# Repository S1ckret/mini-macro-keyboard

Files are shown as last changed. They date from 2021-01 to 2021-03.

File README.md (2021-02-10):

# mini-macro-keyboard

View this project on [CADLAB.io](https://cadlab.io/project/23724). 

## Cloning

After cloning you need to configure (localy to repository) commit message template and init submodules. This will **NOT** override your global configuration.

```sh
git clone https://github.com/S1ckret/mini-macro-keyboard.git

cd mini-macro-keyboard

git config commit.template ./.git-commit-temlate

git submodule update --init
```

You are ready to work!

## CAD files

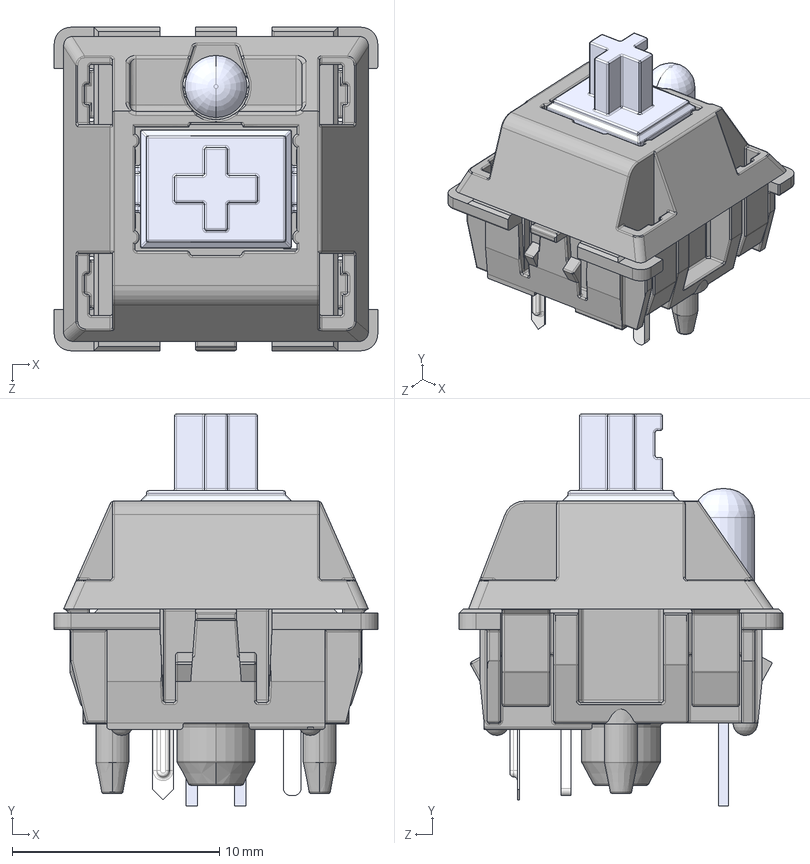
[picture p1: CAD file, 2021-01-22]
hw/mini-macro-keyboard-eco/models/MX.STEP
15.6 x 18.9 x 15.6 mm
MX 轴 按键′_ü___¨1
MX 轴 轴体áì_¨￠¨__
MX粣 拸簽LEDLEDLED
MX轴 轴体 底部 μ×2__默认_á2____è_
针脚___默认__è_

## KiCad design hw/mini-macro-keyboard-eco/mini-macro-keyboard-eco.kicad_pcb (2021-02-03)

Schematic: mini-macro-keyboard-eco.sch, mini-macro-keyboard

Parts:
C0, C1: 12p; C_0402_1005Metric; LCSC Part # C1547
C2, C3, C7: 100n; C_0402_1005Metric; LCSC Part # C1525
C4: 4.7u; C_0402_1005Metric; LCSC Part # C19666
C5, C6: 1u; C_0402_1005Metric; LCSC Part # C52923
D1, D2, D3: BLUE; LED_0603_1608Metric; LCSC Part # C72041
H1, H2, H3, H4: MountingHole_Pad; MountingHole_2.2mm_M2_ISO7380_Pad
J0: USB; USB_Micro-B_Molex-105017-0001
J1: DEBUG_SWD; PinHeader_1x04_P2.54mm_Horizontal
R0: 47; R_0402_1005Metric; LCSC Part # C25792
R1, R2, R3: 330; R_0603_1608Metric; LCSC Part # C23138
R5, R6: 10k; R_0402_1005Metric; LCSC Part # C25744
SW1, SW2, SW3: SW_Cherry_MX_1.00u_PCB
SW5: LAYOUT; SW_SPDT_PCM12
SW6: BACKLIGHT; SW_SPDT_PCM12
U1: USBLC6-2SC6; SOT-23-6; LCSC Part # C7519
U2: XC6206P322MR; SOT-23; LCSC Part # C5446
U3: STM32F070F6P6; TSSOP-20_4.4x6.5mm_P0.65mm; LCSC Part # C86951
Y1: 16 MHz; Crystal_SMD_3225-4Pin_3.2x2.5mm; LCSC Part # C13738

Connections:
+3V3: C2.1, C3.1, C4.1, C6.1, C7.1, J1.1, SW5.1 (A), SW6.1 (A), U2.2 (VO), U3.5 (VDDA), U3.16 (VDD)
+5V: C5.1, J0.1 (VBUS), U1.5 (VBUS), U2.3 (VI)
GND: C0.1, C1.1, C2.2, C3.2, C4.2, C5.2, C6.2, C7.2, H1.1, H2.1, H3.1, H4.1, J0.4 (ID), J0.5 (GND), J1.4, R1.2, R2.2, R3.2, SW1.1, SW2.1, SW3.1, SW5.3 (C), SW6.3 (C), U1.2 (GND), U2.1 (GND), U3.1 (BOOT0), U3.15 (VSS), Y1.2, Y1.4
LED_1: D1.2 (A), U3.9 (PA3)
LED_2: D2.2 (A), U3.7 (PA1)
LED_3: D3.2 (A), U3.6 (PA0)
unnamed: D1.1 (K), R1.1
unnamed: D2.1 (K), R2.1
unnamed: D3.1 (K), R3.1
unnamed: R5.2, SW5.2 (B)
unnamed: R6.2, SW6.2 (B)
OSC_IN: C0.2, U3.2 (PF0), Y1.1
OSC_OUT: C1.2, U3.3 (PF1), Y1.3
SWCLK: J1.3, U3.20 (PA14)
SWDIO: J1.2, U3.19 (PA13)
SW_1: SW1.2, U3.13 (PA7)
SW_2: SW2.2, U3.12 (PA6)
SW_3: SW3.2, U3.11 (PA5)
SW_BACKLIGHT: R6.1, U3.10 (PA4)
SW_LAYOUT: R5.1, U3.14 (PB1)
USB_CONN_D+: J0.3 (D+), U1.3 (I/O2)
USB_CONN_D-: J0.2 (D-), U1.1 (I/O1)
USB_D+: U1.4 (I/O2), U3.18 (PA10/PA12)
USB_D-: U1.6 (I/O1), U3.17 (PA9/PA11)

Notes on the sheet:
Oscillator 16 MHz
USB 2.0 FS
Low dropout regulator (100 mA max)
STM32 Microcontroller
LEDs
Mechanical key switches
Debug SWD connector
Note: STM32F070F6P6 has internal D+ pull up resistor
Switches
Note: Each pin will have internal pull-up resistor
Mounting Holes

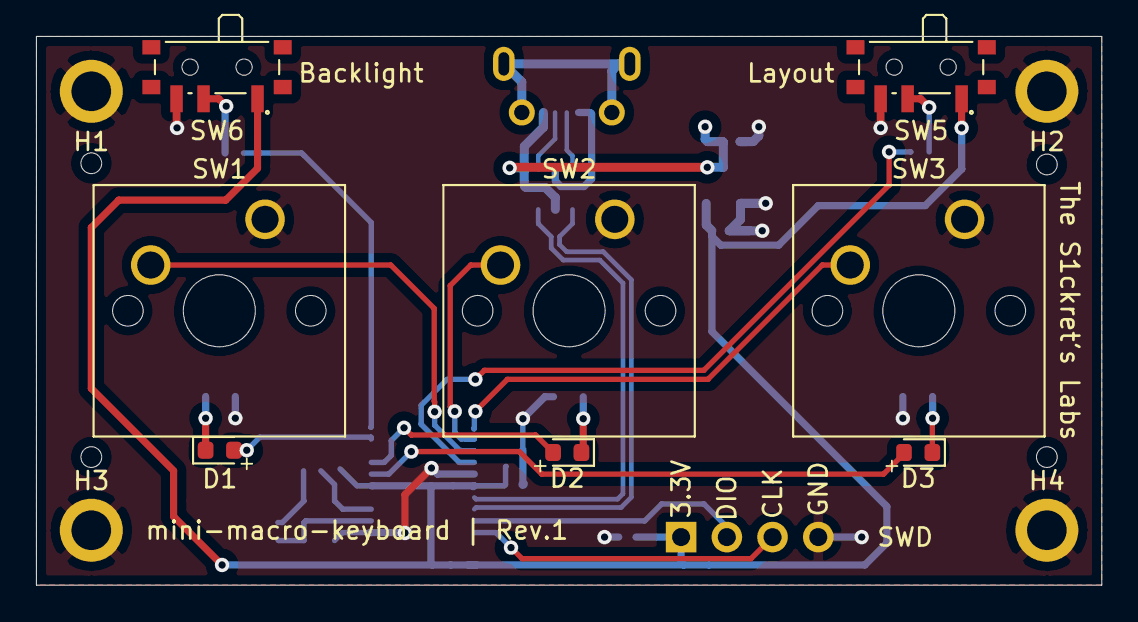
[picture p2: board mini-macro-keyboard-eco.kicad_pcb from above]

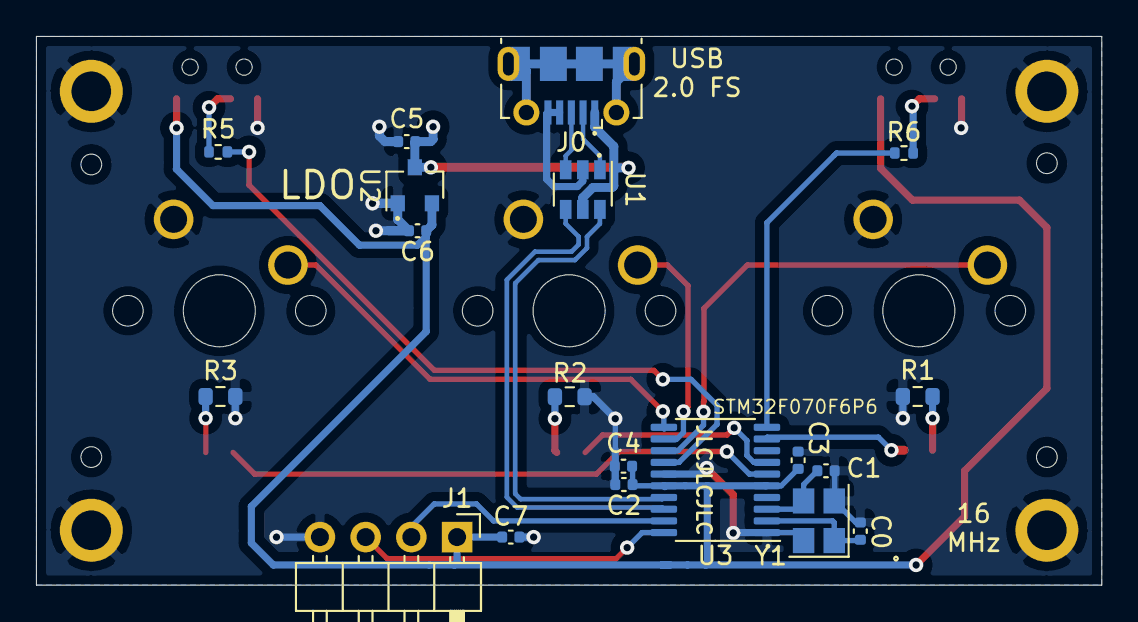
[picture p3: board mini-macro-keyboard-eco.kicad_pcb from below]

Board: 2 copper layers, 59.2 x 30.5 mm, 31 parts (19 on the bottom side), 24 nets.

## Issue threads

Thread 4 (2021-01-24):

HW: Fill top plate with ground

S1ckret, 2021-01-24:
It is wrong filling top plate with VCC

Closed 2021-02-03.

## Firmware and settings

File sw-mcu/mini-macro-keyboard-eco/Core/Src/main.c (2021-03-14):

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
/* Includes ------------------------------------------------------------------*/
#include "main.h"
#include "usb_device.h"
#include "event/modules/e_module_backlight.h"
#include "event/modules/e_module_core.h"
#include "event/modules/e_module_timers.h"
#include "event/modules/e_module_key.h"
#include "event/modules/e_module_keyboard.h"
#include "event/modules/e_module_report_codec.h"

void SystemClock_Config(void);
static void MX_GPIO_Init(void);
/**
  * @brief  The application entry point.
  * @retval int
  */
int main(void)
{
  /* MCU Configuration--------------------------------------------------------*/

  /* Reset of all peripherals, Initializes the Flash interface and the Systick. */
  HAL_Init();

  /* Configure the system clock */
  SystemClock_Config();

  /* Initialize all configured peripherals */
  MX_GPIO_Init();
  MX_USB_DEVICE_Init();
  /* USER CODE BEGIN 2 */
  struct e_module *mod_table[10];
  uint8_t stack[256];
  uint8_t qstack[2048];
  e_core_ctor(mod_table, 10, qstack, 2048, stack, 256);

  struct e_timer *timers[5];
  e_module_timers_ctor(timers, 5);

  struct e_module_backlight mod_backlight;
  e_pmod_backlight = &mod_backlight;
  e_module_backlight_ctor(&mod_backlight, "BCKL");

  struct e_module_key mod_switch_backlight;
  e_pmod_switch_backlight = &mod_switch_backlight;
  e_module_key_ctor(&mod_switch_backlight,
                      "SW_BCKL",
                      DRV_SWITCH_BACKLIGHT,
                      SIG_BACKLIGHT_ON,
                      SIG_BACKLIGHT_OFF,
                      e_pmod_backlight);

  struct e_module_keyboard mod_keyboard;
  e_pmod_keyboard = &mod_keyboard;
  e_module_keyboard_ctor(&mod_keyboard, "KEYBOARD");

  struct e_module_key mod_switch_layout;
  e_pmod_switch_layout = &mod_switch_layout;
  e_module_key_ctor(&mod_switch_layout,
                      "SW_LAYOUT",
                      DRV_SWITCH_LAYOUT,
                      SIG_LAYOUT_ON,
                      SIG_LAYOUT_OFF,
                      e_pmod_keyboard);

  struct e_module_key mod_switch_key_1;
  e_pmod_key_1 = &mod_switch_key_1;
  e_module_key_ctor(&mod_switch_key_1,
                      "SW_KEY_1",
                      DRV_KEY_1,
                      SIG_KEY_PRESSED,
                      SIG_KEY_RELEASED,
                      e_pmod_keyboard);

  struct e_module_key mod_switch_key_2;
  e_pmod_key_2 = &mod_switch_key_2;
  e_module_key_ctor(&mod_switch_key_2,
                      "SW_KEY_2",
                      DRV_KEY_2,
                      SIG_KEY_PRESSED,
                      SIG_KEY_RELEASED,
                      e_pmod_keyboard);

  struct e_module_key mod_switch_key_3;
  e_pmod_key_3 = &mod_switch_key_3;
  e_module_key_ctor(&mod_switch_key_3,
                      "SW_KEY_3",
                      DRV_KEY_3,
                      SIG_KEY_PRESSED,
                      SIG_KEY_RELEASED,
                      e_pmod_keyboard);

  struct e_module_report_codec mod_report_codec;
  e_pmod_report_codec = &mod_report_codec;
  e_module_report_codec_ctor(&mod_report_codec, "CODEC");

  e_core_add_module((struct e_module*) &mod_backlight);
  e_core_add_module((struct e_module*) &mod_switch_backlight);
  e_core_add_module((struct e_module*) &mod_keyboard);
  e_core_add_module((struct e_module*) &mod_switch_layout);
  e_core_add_module((struct e_module*) &mod_switch_key_1);
  e_core_add_module((struct e_module*) &mod_switch_key_2);
  e_core_add_module((struct e_module*) &mod_switch_key_3);
  e_core_add_module((struct e_module*) &mod_report_codec);

  e_core_loop();
  /* USER CODE END 2 */

  /* Infinite loop */
  /* USER CODE BEGIN WHILE */
  while (1)
  {
    /* USER CODE END WHILE */

    /* USER CODE BEGIN 3 */
  }
  /* USER CODE END 3 */
}

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


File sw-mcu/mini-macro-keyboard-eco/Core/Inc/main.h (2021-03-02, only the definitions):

#define LED_3_Pin GPIO_PIN_0
#define LED_3_GPIO_Port GPIOA
#define LED_2_Pin GPIO_PIN_1
#define LED_2_GPIO_Port GPIOA
#define LED_1_Pin GPIO_PIN_3
#define LED_1_GPIO_Port GPIOA
#define SW_BACKLIGHT_Pin GPIO_PIN_4
#define SW_BACKLIGHT_GPIO_Port GPIOA
#define SW_BACKLIGHT_EXTI_IRQn EXTI4_15_IRQn
#define SW_3_Pin GPIO_PIN_5
#define SW_3_GPIO_Port GPIOA
#define SW_3_EXTI_IRQn EXTI4_15_IRQn
#define SW_2_Pin GPIO_PIN_6
#define SW_2_GPIO_Port GPIOA
#define SW_2_EXTI_IRQn EXTI4_15_IRQn
#define SW_1_Pin GPIO_PIN_7
#define SW_1_GPIO_Port GPIOA
#define SW_1_EXTI_IRQn EXTI4_15_IRQn
#define SW_LAYOUT_Pin GPIO_PIN_1
#define SW_LAYOUT_GPIO_Port GPIOB
#define SW_LAYOUT_EXTI_IRQn EXTI0_1_IRQn

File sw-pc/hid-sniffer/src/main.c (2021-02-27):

#include <stdio.h>
#include <string.h>
#include <stdlib.h>
#include <stdint.h>
#include "hidapi.h"

#define KEYBOARD_VENDOR_ID (0x0483u)
#define KEYBOARD_PRODUCT_ID (0x5750u)

#define REPORT_MAX_SIZE (9U)
#define REPORT_SYNC_MAX_COUNT (6U)

void print_hid_info(struct hid_device_info *dev);
void print_report_content(unsigned char *report, unsigned report_size);

struct hid_device_info *find_keyboard(struct hid_device_info *devs);

struct report_out_create_macro {
	uint8_t report_id;
	uint8_t key_address;
	uint8_t dynamic_flags;
	uint8_t key[6];
};

int main(int argc, char* argv[])
{
	printf("Type `exit` to exit.\n");
	if (hid_init()) return -1;
	printf("HID API has been inited...\n");
	
	hid_device *keyboard = hid_open_path("\\\\?\\hid#vid_0483&pid_5750&col01#6&4756b74&0&0000#{4d1e55b2-f16f-11cf-88cb-001111000030}");
	if (!keyboard) {
		printf("The mini-macro-keyboard wasn't found! Please try again.\n");
		return -1;
	}
	printf("The mini-macro-keyboard was found!\n");

	while (1)
	{
		printf("Input 4-9 bytes in decimal comma/space separatted: \n");

		char *in_s = NULL;
		uint32_t in_s_size = 0U;
		getline(&in_s, &in_s_size, stdin);

		if (strcmp(in_s, "exit\n") == 0) break;

		uint8_t raw_report[REPORT_MAX_SIZE] = {0};
		char *token = NULL;
		const char delimeters[] = " ,[]";
		uint8_t i = 0U;

		token = strtok(in_s, delimeters);
		while(token != NULL && i < REPORT_MAX_SIZE) {
			raw_report[i] = atoi(token);
			i++;
			
			token = strtok(NULL, delimeters);
		}
		free(in_s);

		while (i < REPORT_MAX_SIZE) {
			raw_report[i] = 0U;
			i++;
		}
		
		printf("Trying to send output report...\n");
		print_report_content((uint8_t *) &raw_report, REPORT_MAX_SIZE);
		hid_write(keyboard, (uint8_t *) &raw_report, REPORT_MAX_SIZE);
		int status = hid_write(keyboard, (uint8_t *) &raw_report, 9);
		printf("Status: %d, %ls\n", status, hid_error(keyboard));

		if (raw_report[0] == 'S') {
			for (uint8_t i = 0; i < REPORT_SYNC_MAX_COUNT; ++i) {
				uint8_t in_report[REPORT_MAX_SIZE] = {0};
				printf("Trying read input report...\n");
				int in_status = hid_read_timeout(keyboard, (uint8_t *) &in_report, REPORT_MAX_SIZE, 2000);
				printf("Status: %d, %ls\n", status, hid_error(keyboard));
				print_report_content((uint8_t *) &in_report, REPORT_MAX_SIZE);
			}
		}
	}
	
	hid_close(keyboard);

	return 0;
}

void print_hid_info(struct hid_device_info *dev) {
	printf("  VID: 0x%04hx", dev->vendor_id);
	printf("  PID: 0x%04hx\n", dev->product_id);
	printf("  serial_number: %ls", dev->serial_number);
	printf("  Manufacturer: %ls\n", dev->manufacturer_string);
}

void print_report_content(unsigned char *report, unsigned report_size) {
	printf("Report content: [");
	printf("%03d", report[0]);
	for (unsigned i = 1U; i < report_size; ++i) {
		printf(", %03d", report[i]);
	}
	printf("]\n");
}

struct hid_device_info *find_keyboard(struct hid_device_info *devs) {
	struct hid_device_info *cur_dev = devs;
	printf("Looking for device with VID: %04hx PID: %04hx...\n", KEYBOARD_VENDOR_ID, KEYBOARD_PRODUCT_ID);
	struct hid_device_info *keyboard = NULL;
	while (cur_dev) {
		printf("Device found:\n");
		if (cur_dev->vendor_id == KEYBOARD_VENDOR_ID && cur_dev->product_id == KEYBOARD_PRODUCT_ID) {
			keyboard = cur_dev;
		}
		cur_dev = cur_dev->next;
	}

	return keyboard;
}

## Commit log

2021-01-08 feat(hw): add kicad project
    [mini-macro-keyboard.kicad_pcb, mini-macro-keyboard.sch]
2021-01-09 feat(hw): add stm32f103c8t6 to the schematic
    [mini-macro-keyboard.sch]
2021-01-09 feat(hw): add power supply
    [mini-macro-keyboard.sch]
2021-01-09 feat(hw): add boot0 switch
    [mini-macro-keyboard.sch]
2021-01-09 feat(hw): add nrst switch
    [mini-macro-keyboard.sch]
2021-01-09 feat(hw): add pin labels
    [mini-macro-keyboard.sch]
2021-01-09 feat(hw): add crystal to the schematic
    [mini-macro-keyboard.sch]
2021-01-09 fix(hw): remove VBAT connection
    [mini-macro-keyboard.sch]
2021-01-09 feat(hw): add usblc6 protection
    [mini-macro-keyboard.sch]
2021-01-09 feat(hw): create library with mp2359 dc/dc buck
2021-01-09 feat(hw): add buck dc/dc converter to the schematic
    [mini-macro-keyboard.sch]
2021-01-09 fix(hw): add resitors after the usb protection
    [mini-macro-keyboard.sch]
2021-01-09 feat(hw): add leds
    [mini-macro-keyboard.sch]
2021-01-09 feat(hw): add connector for st-link
    [mini-macro-keyboard.sch]
2021-01-09 fix(hw): replace spst to push button on the nrst line
    [mini-macro-keyboard.sch]
2021-01-09 style(hw): change label to power source
    [mini-macro-keyboard.sch]
2021-01-09 style(hw): rename push switch
    [mini-macro-keyboard.sch]
2021-01-09 feat(hw): add switches
    [mini-macro-keyboard.sch]
2021-01-10 style(hw): devide schematic into sections
    [mini-macro-keyboard.sch]
2021-01-10 feat(hw): annotate schematic
    [mini-macro-keyboard.sch]
2021-01-10 fix(hw): add ground to the buck converter
    [mini-macro-keyboard.sch]
2021-01-10 style(hw): rename connector
    [mini-macro-keyboard.sch]
2021-01-10 feat(hw): replace buck converter with ldo
    [mini-macro-keyboard.sch]
2021-01-10 chore(hw): remove library with buck converter
2021-01-10 feat(hw): add project with stm32f070f6p6
    It is called eco, because it is economically better for my wallet
    [mini-macro-keyboard-eco.kicad_pcb, mini-macro-keyboard-eco.sch]
2021-01-22 chore(hw): rescue eco schematic
    New version of the kicad is used
    [mini-macro-keyboard-eco.sch]
2021-01-22 feat(hw): assign footprints
    [mini-macro-keyboard-eco.sch]
2021-01-22 feat(hw): change design rules
    [mini-macro-keyboard-eco.kicad_pcb]
2021-01-22 feat(hw): load netlist
    [mini-macro-keyboard-eco.kicad_pcb]
2021-01-22 feat(hw): add rough layout
    [mini-macro-keyboard-eco.kicad_pcb]
2021-01-22 style(hw): rename value fields
    [mini-macro-keyboard-eco.sch]
2021-01-22 fix(hw): remove debounce circuit from the mechanical switches
    [mini-macro-keyboard-eco.kicad_pcb, mini-macro-keyboard-eco.sch]
2021-01-22 feat(hw)!: remove reset push button
    BREAKING CHANGE:
    I remove the reset schematic becauce it uses a lot of space and
    I won't mess with usb bootloaders in the future. Also I don't know
    how to update software on the MCU in the user-friendly manner.
    [mini-macro-keyboard-eco.kicad_pcb, mini-macro-keyboard-eco.sch]
2021-01-22 feat(hw)!: remove boot switch
    I have removed boot switch because I don't expect to use another
    bootloaders
    [mini-macro-keyboard-eco.kicad_pcb, mini-macro-keyboard-eco.sch]
2021-01-22 feat(hw): reanotate schematic
    [mini-macro-keyboard-eco.kicad_pcb, mini-macro-keyboard-eco.sch]
2021-01-22 feat(hw): place components closer
    [mini-macro-keyboard-eco.kicad_pcb]
2021-01-22 feat(hw): add mounting holes
    [mini-macro-keyboard-eco.kicad_pcb, mini-macro-keyboard-eco.sch]
2021-01-22 feat(hw): improve layout
    [mini-macro-keyboard-eco.kicad_pcb]
2021-01-22 feat(hw): add edges
    [mini-macro-keyboard-eco.kicad_pcb]
2021-01-22 feat(hw): move usb-b to the back layer
    [mini-macro-keyboard-eco.kicad_pcb]
2021-01-22 feat(hw): add rooting
    [mini-macro-keyboard-eco.kicad_pcb, mini-macro-keyboard-eco.sch]
2021-01-22 feat(hw): add filled power and ground plates
    [mini-macro-keyboard-eco.kicad_pcb]
2021-01-22 feat(hw): add silkscreen
    [mini-macro-keyboard-eco.kicad_pcb]
2021-01-22 feat(hw): add cherry mx 3d model
    [MX.STEP, mini-macro-keyboard-eco.kicad_pcb]
2021-01-22 fix(hw): reroute some traces
    [mini-macro-keyboard-eco.kicad_pcb]
2021-02-03 fix(hw, #3): remove R0 resistor
    [mini-macro-keyboard-eco.kicad_pcb, mini-macro-keyboard-eco.sch]
2021-02-03 fix(hw, #4): remove 3.3v plate filling
    [mini-macro-keyboard-eco.kicad_pcb]
2021-02-03 feat(hw): add jlcpcb parts number
    [mini-macro-keyboard-eco.sch]
2021-02-03 feat(sw-mcu): add key driver
2021-02-03 feat(sw-mcu): add backlight interrupt processing
2021-02-10 feat(sw-mcu): add switches to the drv_switch
2021-02-10 feat(sw-mcu): improve switch driver
2021-02-10 feat(sw-mcu): fix switch driver
    [drv_switch.c]
2021-02-10 feat(sw-mcu): add switch modules
2021-02-10 feat(sw-mcu): add backlight switch module
2021-02-10 feat(sw-mcu): handle interrupts for backlight switch
2021-02-10 feat(sw-mcu): add key switches
2021-02-10 feat(sw-mcu): fix keys interrupt
    [main.c]
2021-02-10 feat(sw-mcu): add keys interrupt handling
2021-02-10 feat(sw-mcu): add led toggle on key press
2021-02-14 Revert "feat(sw-mcu)!: add hardcoded report handling"
    This reverts commit 77f530ed609c5c58355a8f68c19c6d08ad203524.
    [mini-macro-keyboard.ioc]
2021-02-14 Revert "feat(sw-mcu)!: add hardcoded report codec module"
    This reverts commit a50b0d7ca3c17dbbea6203bb55fcfa5dec7573cc.
    [main.c]
2021-02-20 feat(sw-mcu): add led test indication
2021-02-27 feat(hid-sniffer): fix device path to open
    TODO: automaticaly detect path
    [main.c]
2021-02-27 feat(sw-mcu): bump up timer quantity to 6
2021-03-02 feat(sw-mcu-eco): add project for STM32F070
2021-03-02 feat(sw-mcu-eco): move code to the STM32F070
2021-03-02 feat(sw-mcu-eco): correct code for STM32F070
    [drv_led.c, drv_switch.c, main.c]
2021-03-02 feat(sw-mcu-eco): add main init code for STM32F070
2021-03-02 feat(sw-mcu-eco): move interrupt related code to the STM32F070
2021-03-02 feat(sw-mcu-eco): move report descriptor to the STM32F070
2021-03-14 fix(sw-mcu-eco): fix type table and timer
    [main.c]
2021-03-14 feat(sw-mcu-eco): add layout switch

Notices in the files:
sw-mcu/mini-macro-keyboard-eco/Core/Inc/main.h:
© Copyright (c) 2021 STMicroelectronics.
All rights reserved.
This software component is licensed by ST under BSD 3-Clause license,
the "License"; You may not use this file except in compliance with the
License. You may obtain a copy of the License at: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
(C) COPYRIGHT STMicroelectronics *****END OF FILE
